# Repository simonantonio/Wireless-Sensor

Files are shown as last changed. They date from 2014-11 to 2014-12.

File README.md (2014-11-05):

Wireless Sensor Host Board
=========

This is a board used to implement wireless reporting of various sensors

Suggested Sensor Modules
---  

 - DHT22 - Temperature & Humidity  
 - TSOP4838 - IR Sensor (32khz carrier)  
 - Photo Resistor - Basic Light Levels  
 - Pulse Sensing - For use with hall effect sensors or weather stations such as [Spark Fun's Weather Station](https://www.sparkfun.com/products/8942)
 - BMP180 - Barometer & Temperature
 - Battery Voltage Monitoring
 
Results can then be transmitted to a receiver using a NRF24L01+ 

The board aims to be a low power long term sensor platform, potentially being powered from a LIPO battery directly or using a step down module such as the [Pololu Step Down Voltage Regulator](http://www.pololu.com/product/2097) 

Licensed Under the [Creative Commons Attribution-ShareAlike 3.0 Unported (CC-BY-SA 3.0)](https://creativecommons.org/licenses/by-sa/3.0/) and designed with the OSHW concepts in mind

 Intial Board Prototypes are being producted via the awesome service at [Dirty PCB's](http://dirtypcbs.com/)  
 Feel free to buy them [here](http://dirtypcbs.com/view.php?share=2637&accesskey=f92450b07b6b3961496835b5062594b2)  for $25.00USD

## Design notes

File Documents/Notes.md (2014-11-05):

Project Notes
=========

This is a very basic document containing thoughts, ideas and some notes on the wireless sensor board  
   
You will need 
----
 - ISP programmer
 - Soldering Skills (there is a reasonable amount of SMD parts sorry)
 - Parts (You should be able to get a decent amount from ebay)
 - Programming Skills. 
 
Notes
-----
Feel free to use the Arduino IDE with your ISP programmer,   
I suggest the [USBtinyISP](https://learn.adafruit.com/usbtinyisp) by adafruit
 
Project will be based fairly strongly on my experience with arduino. But will function as a standalone. 
 
TODO
----
Write the damn program.  
Setup a base station  
Debug  
Test Hardware  
Get PCB  - in progress, ordered intial prototypes on 5th November 2014  
Get Parts - in progress, ordered several parts from ebay. Need aditional minerals (or funds) to order more bits and pieces  
Write proper documentation and instructions  
Improve board layout (ideally smaller than 5x5)  
Add a through hole component version of the board to make life easier  

??  
Profit

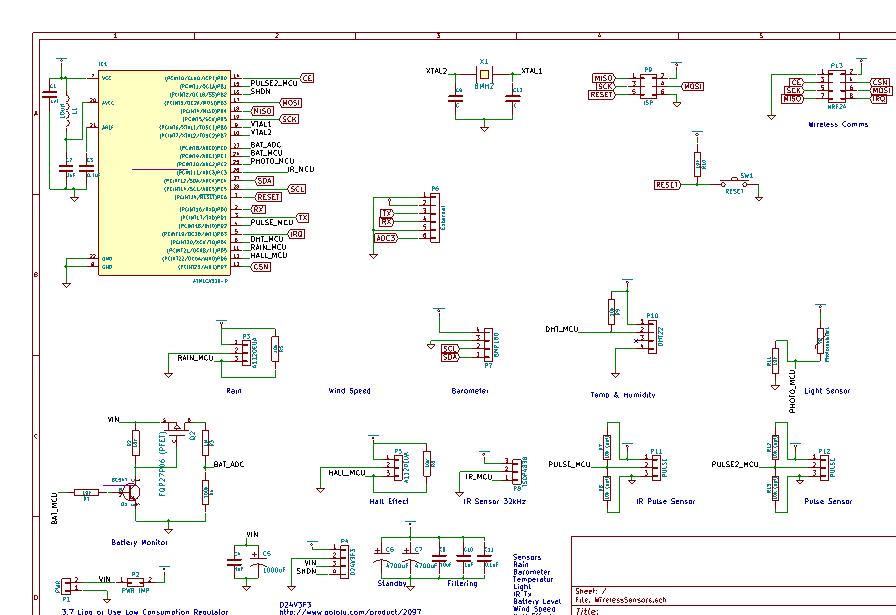
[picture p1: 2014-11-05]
Documents/Schematic.png

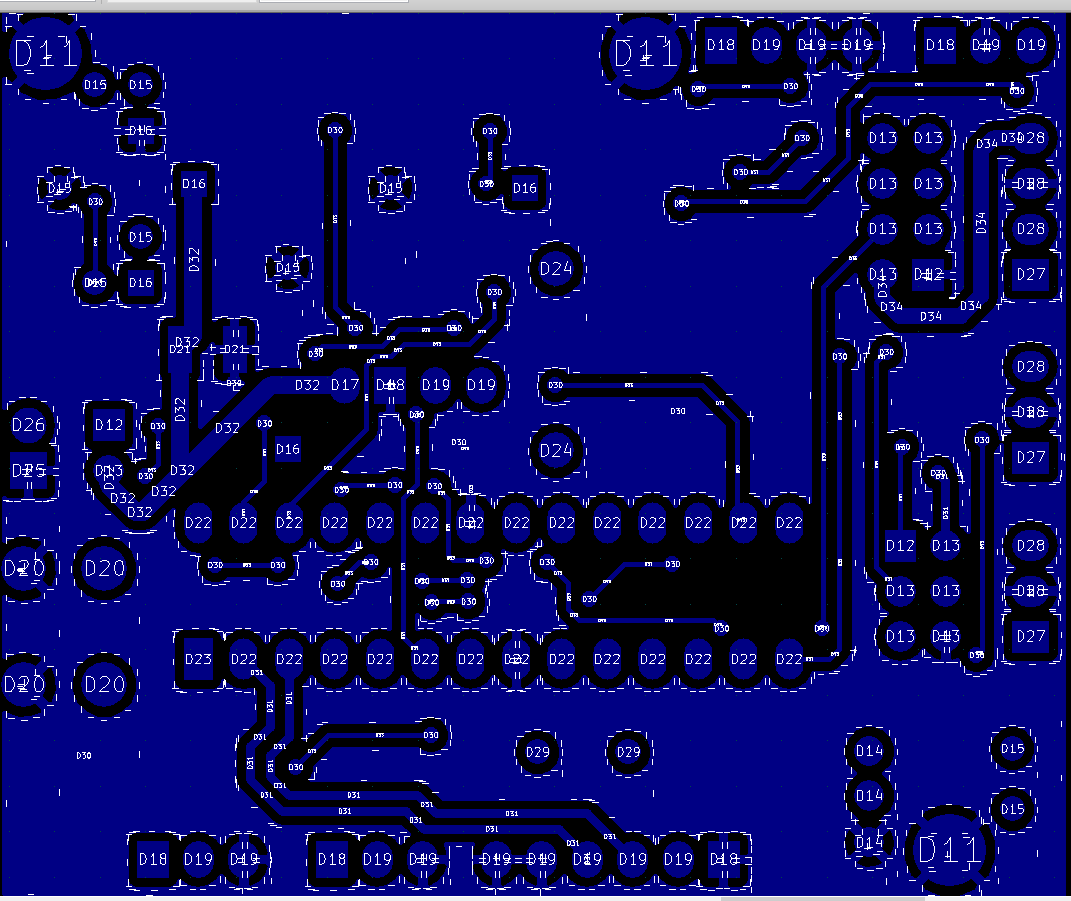
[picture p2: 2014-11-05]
Documents/Board-Cu-Bottom.png

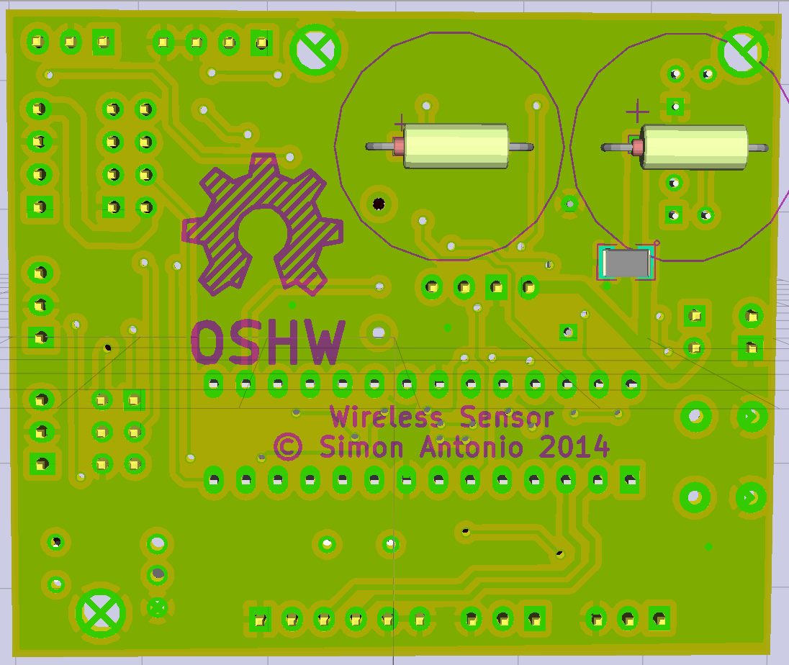
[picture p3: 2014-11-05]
Documents/Board-Bottom-3d.png

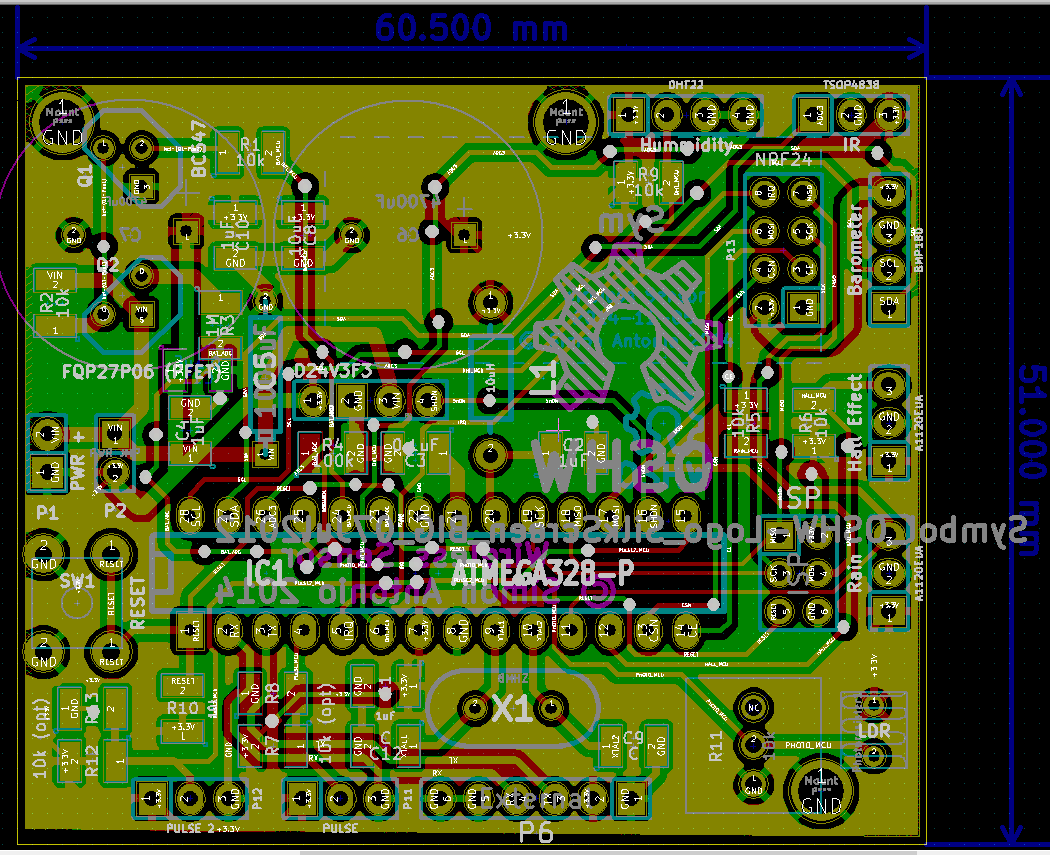
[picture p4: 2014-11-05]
Documents/Board-2d.png

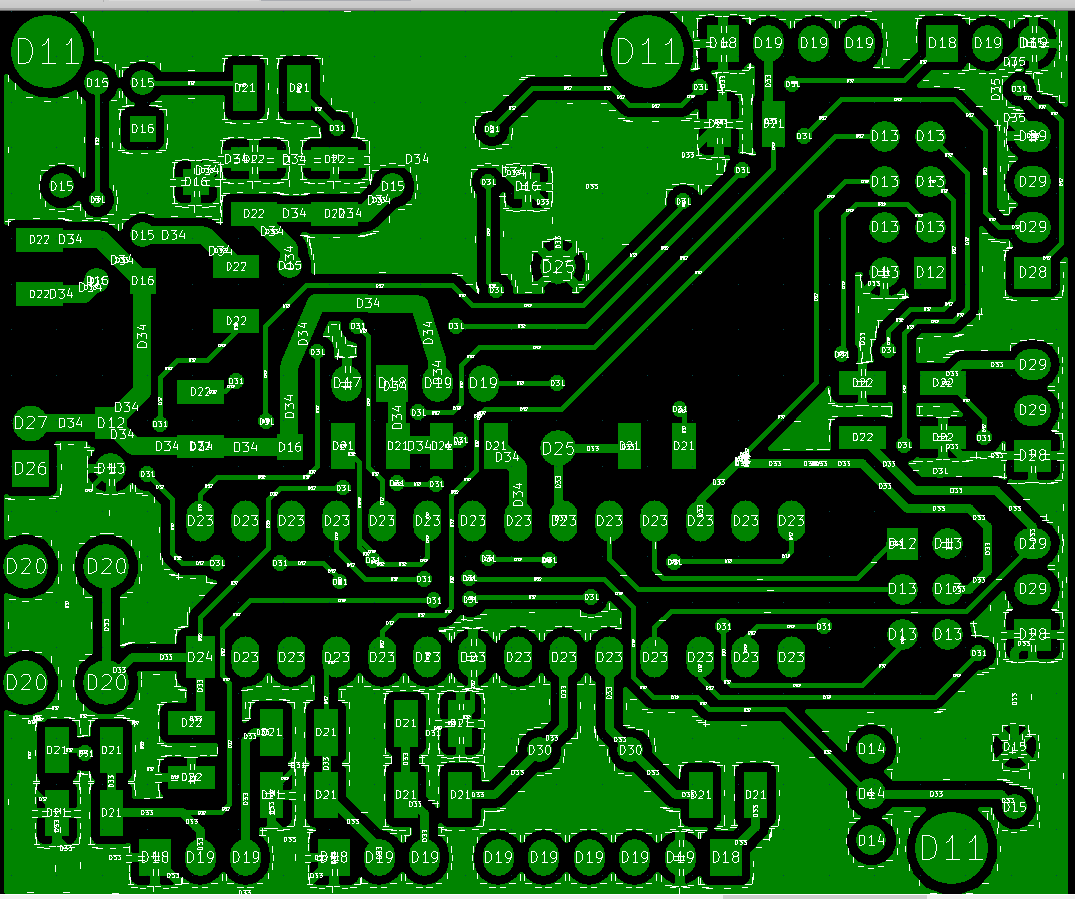
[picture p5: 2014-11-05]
Documents/Board-Cu-Top.png

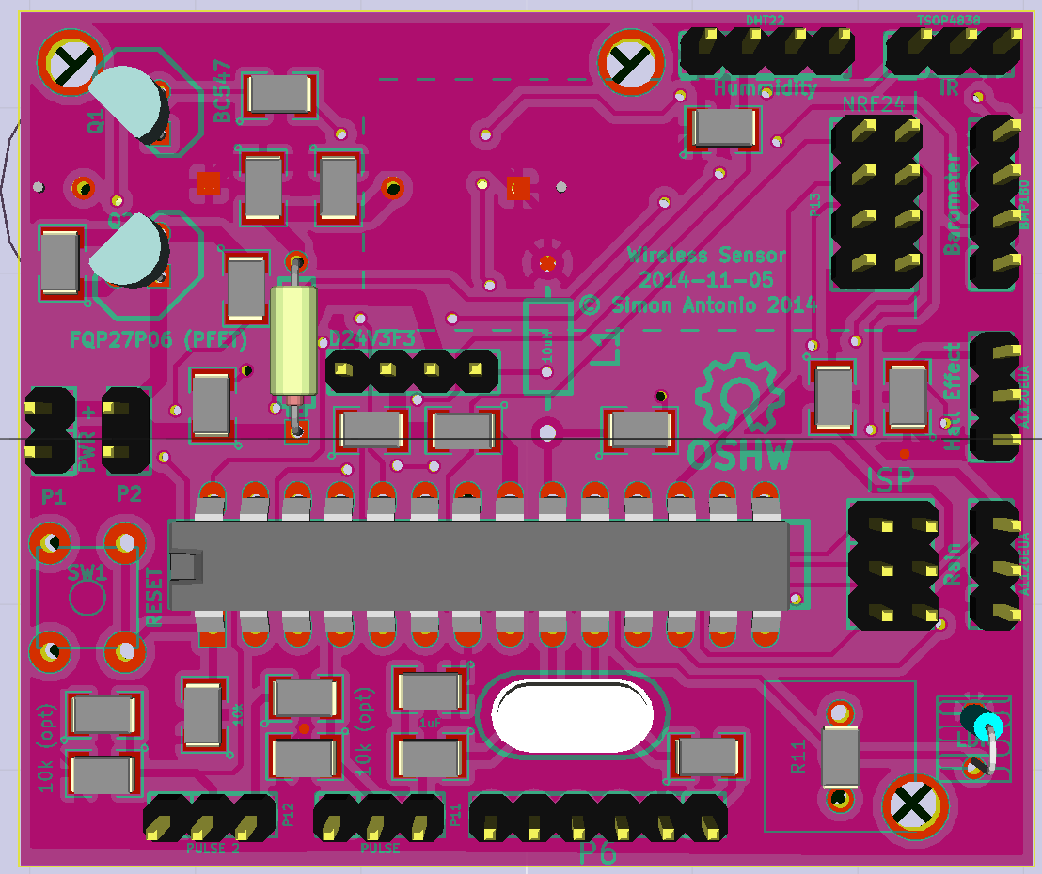
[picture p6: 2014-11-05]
Documents/Board-Top-3d.png

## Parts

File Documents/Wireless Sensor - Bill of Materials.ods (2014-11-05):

Label | Part | Footprint | Description | Link | Quantity | Price | Own Stock
C1,C2,C4,C10 | 1uF Ceramic Capacitor | 1210 - SMD |  |  | 4 |  | y
C3, C11 | 0.1uF Ceramic Cap | 1210 - SMD | can fit 805's |  | 2 |  | y
C5 | 1000uF Electrolitic | TH - up to CP4 | 25V |  | 1 |  | y
C6, C7 | 4700uF Electrolitic Cap | TH - up to CP5 | 10V |  | 2 |  | y
C9, C12 | 20pF Ceramic Cap | 1210 - SMD | to suit crystal |  | 2 |  | y
IC1 | ATMEGA328 | DIP 28 |  |  | 1
L1 | 10uH Inductor | TH | optional filter inductor
P1,P2 | 2 Pin header 0.1" |  |  |  | 2
P3,P5,P8,P11,P12 | 3 Pin header 0.1" |  |  |  | 5
P4,P7,P10 | 4 Pin header 0.1" |  |  |  | 3
P6 | 6 Pin header 0.1" |  |  |  | 1
P9 | 2x3 Pin female 0.1" |  | ISP header |  | 1
P13 | 2x4 Pin female 0.1" |  | Wireless NRF24 Connector |  | 1
Q1 | BC547 | TO92 | NPN Transistor
Q2 | FQP27P06 | TO92 | PFET
LDR1 | Photo Resistor 100k | TH | 100k, or 10k |  | 1
R1,R2,R5,R6,R9,R10 | 10k Resistor | 1210 - SMD
R7,R8,R12,R13 | 10k Resistor | 1210 - SMD | Optional
R3 | 1M Resistor | 1210 - SMD
R4 | 100k Resistor | 1210 - SMD
R11 | 10k Trimpot | TH | Three pins in a row
SW1 | Switch |  | Reset button
X1 | 8MHz Crystal | HC49 - TH | Optionally 16MHz

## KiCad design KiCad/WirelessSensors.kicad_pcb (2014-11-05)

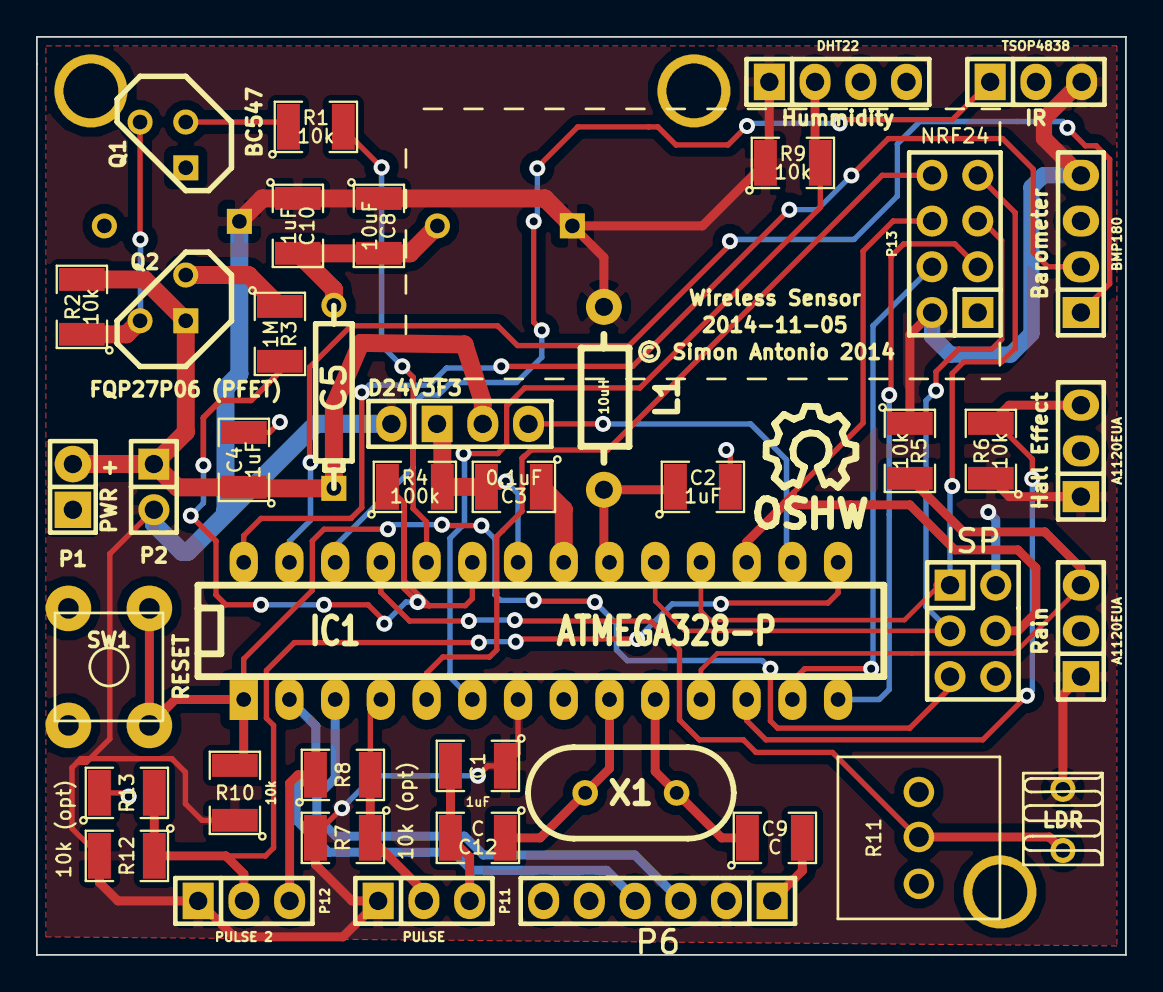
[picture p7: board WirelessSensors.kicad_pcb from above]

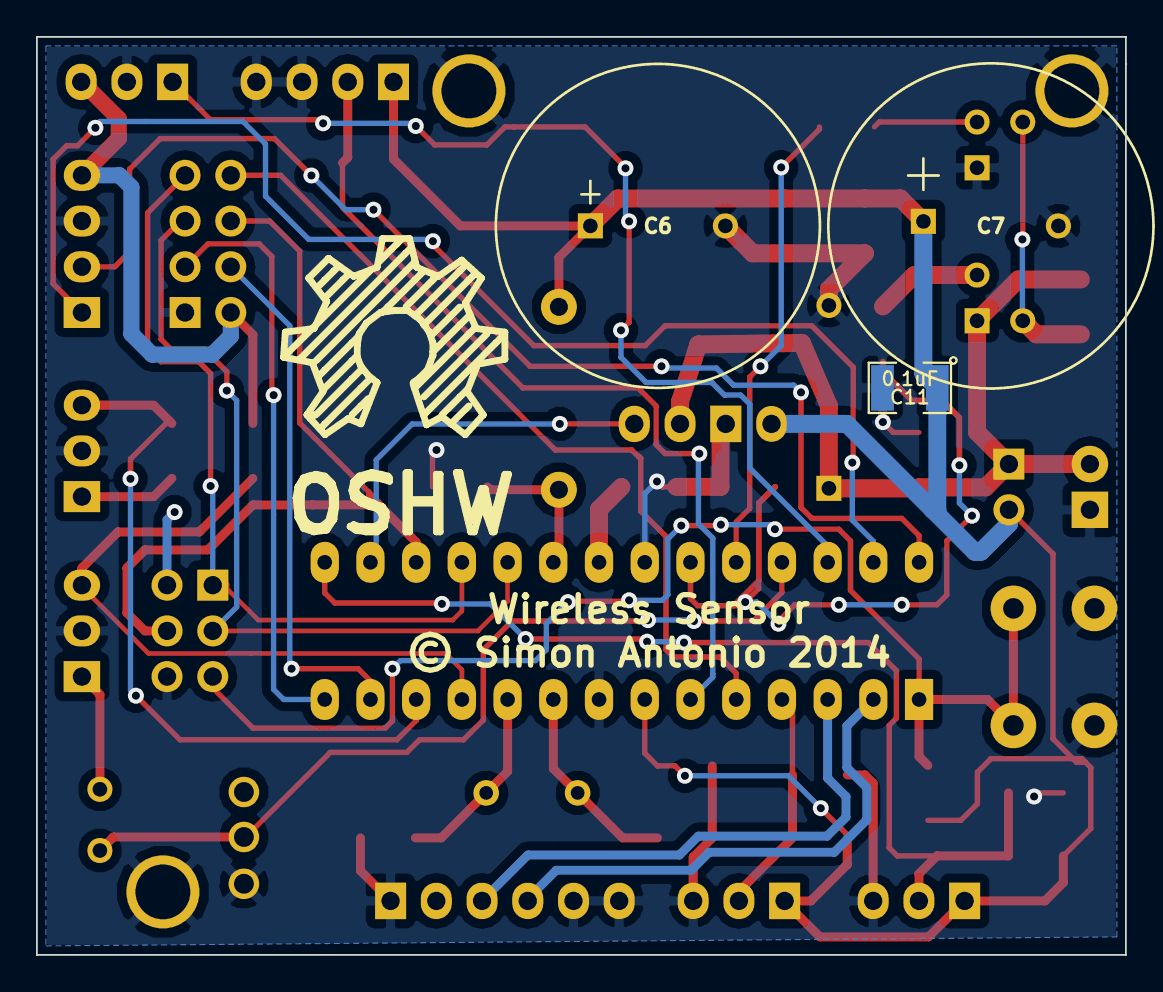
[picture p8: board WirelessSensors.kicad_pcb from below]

Board: 2 copper layers, 60.5 x 51.0 mm, 49 parts (4 on the bottom side), 31 nets.

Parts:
Barometer: BMP180; Pin_Header_Straight_1x04
C1, C2, C4, C10: 1uF; SMD-1210
C3, C11: 0.1uF; SMD-1210
C5: 1000uF; CP4
C6, C7: 4700uF; CP5
C8: 10uF; SMD-1210
C9, C12: C; SMD-1210
Hall Effect: A1120EUA; Pin_Header_Straight_1x03
Hummidity: DHT22; Pin_Header_Straight_1x04
IC1: ATMEGA328-P; DIP-28__300_ELL
IR: TSOP4838; Pin_Header_Straight_1x03
ISP: ISP; Pin_Header_Straight_2x03
L1: 10uH; Choke_Horizontal_RM10mm
Mount: P***; 1pin
Mount#2, Mount#3: P***; 1pin
P1: PWR +; Pin_Header_Straight_1x02
P2: PWR JMP; Pin_Header_Straight_2x01
P4: D24V3F3; Pin_Header_Straight_1x04
P6: External; Pin_Header_Straight_1x06
P11: PULSE; Pin_Header_Straight_1x03
P12: PULSE 2; Pin_Header_Straight_1x03
P13: NRF24; Pin_Header_Straight_2x04
Photoresister1: LDR; R1
Q1: BC547; TO92-123
Q2: FQP27P06 (PFET); TO92GSD
R1, R2, R5, R6, R9, R10, R11: 10k; SMD-1210
R3: 1M; SMD-1210
R4: 100k; SMD-1210
R7, R8, R12, R13: 10k (opt); SMD-1210
Rain: A1120EUA; Pin_Header_Straight_1x03
SW1: RESET; SW_PUSH
Sym: Symbol_OSHW-Logo_SilkScreen_BIG_07Jul2012; Symbol_OSHW-Logo_SilkScreen_BIG
X1: 8MHZ; HC-49V

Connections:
+3.3V: Barometer.4, C1.1, C6.1, C7.1, C8.1, C10.1, C11.1, Hall Effect.1, Hummidity.1, IC1.7, IR.3, ISP.2, L1.1, P2.2, P4.1, P6.2, P11.1, P12.1, P13.2, Photoresister1.1, R5.1, R6.1, R7.2, R9.1, R10.1, R12.2, Rain.1
/BAT_ADC: IC1.23, R3.2, R4.1
/BAT_MCU: IC1.24, R1.2
/DHT_MCU: Hummidity.2, IC1.6, R9.2
/HALL_MCU: Hall Effect.3, IC1.12, R6.2
/PHOTO_MCU: IC1.25, Photoresister1.2, R11.2
/PULSE2_MCU: IC1.15, P12.2, R12.1, R13.2
/PULSE_MCU: IC1.4, P11.2, R7.1, R8.2
/RAIN_MCU: IC1.11, R5.2, Rain.3
/SHDN: IC1.16, P4.4
/VIN: C4.1, C5.1, P1.2, P2.1, P4.3, Q2.S, R2.2
/XTAL1: C12.1, IC1.9, X1.2
/XTAL2: C9.1, IC1.10, X1.1
ADC3: IC1.26, IR.1
CE: IC1.14, P13.3
CSN: IC1.13, P13.4
GND: Barometer.3, C1.2, C2.2, C3.2, C4.2, C5.2, C6.2, C7.2, C8.2, C9.2, C10.2, C11.2, C12.2, Hall Effect.2, Hummidity.3, Hummidity.4, IC1.8, IC1.22, IR.2, ISP.6, Mount.1, Mount#2.1, Mount#3.1, P1.1, P4.2, P6.1, P6.5, P6.6, P11.3, P12.3, P13.1, Q1.3, R4.2, R8.1, R11.1, R13.1, Rain.2, SW1.2
IRQ: IC1.5, P13.8
MISO: IC1.18, ISP.1, P13.7
MOSI: IC1.17, ISP.4, P13.6
unnamed: C2.1, IC1.20, L1.2
unnamed: C3.1, IC1.21
unnamed: Q1.1, Q2.G, R2.1
unnamed: Q1.2, R1.1
unnamed: Q2.D, R3.1
RESET: IC1.1, ISP.5, R10.2, SW1.1
RX: IC1.2, P6.4
SCK: IC1.19, ISP.3, P13.5
SCL: Barometer.2, IC1.28
SDA: Barometer.1, IC1.27
TX: IC1.3, P6.3

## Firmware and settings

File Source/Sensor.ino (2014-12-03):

#include <SPI.h>
#include <Wire.h>
#include <DHT.h>
#include <PinChangeInt.h>

#include <SFE_BMP180.h>

#include <RHReliableDatagram.h>
#include <RH_NRF24.h>

#include <Time.h>

#include "Datagram.h"
#include "BMP180_Manager.h"
#include "Error.h"

/*
	Author:
		S.Antonio 2014-12-03
	Description:
		Board Uses Radio Head library for NRF24L01+ Wireless Transceiver
		NRF24
			CS																	PD7 [D7]
			CE																	PB0 [D8]

		BMP180																	i2c
		DHT22																	PD4 [D4]
		Sparkfun Weather Meters (SEN-08942)
			Rain																PD5 [D5]
			Pulse (add resister to high side R7)	(anometer)					PD2 [D2]
			Wind Vane (wire to ADC3 [IR])										ADC3 [A3]

		Pulse 2	(add resister to high side R12)									PB1	[D9]
		Hall																	PD6 [D6]

		Light Dependant Resister (10k)											ADC2 [A2]
		
		Optional, 
			Battery Monitoring													ADC0 [A0]
			Battery Read (Pull High)											ADC1 [A1]
			Power Shut Down (High = ON, Low = OFF)								PB2 [D10]
				Will last x seconds before caps run out of power in low power mode		-- TODO calculations and watch dog to recharge caps for standby
			TSOP4838 (IR 32kHz carrier)											ADC3 [A3]
	Notes:
		Target Arduino Pro Mini 3.3v 8MHz - Board is based of ATMEGA 328 running at 8MHz
		Either populate the D24V3F3 (pololu 3.3 regulator) or supply clean 3.3v source and add jumper to P2 (PWR_JMP)
		Typically either use the Weather Meter, or the IR sensor, but not both together.

	Libraries:
		http://www.airspayce.com/mikem/arduino/RadioHead/index.html				NRF24
		https://github.com/adafruit/DHT-sensor-library							DHT22
		https://github.com/sparkfun/BMP180_Breakout/archive/master.zip			BMP180
		http://playground.arduino.cc/Code/Time									Time
	Changes:
		N/A
	TODO:
		ppm oscillator drift offset
		remote time set
		remote query
		move user configs to seperate header
*/

//USER Configuration here

//IR or WEATHER - set false for IR sensing

#define IR_PIN A3
#define WS_WIND_DIRECTION A3
#define WS_RAIN 5
#define WS_WIND_SPEED 2

//LDR Pin
#define LDR_PIN A2

//Wireless Setup
#define NRF24_CLIENT_ADDRESS 1
#define NRF24_SERVER_ADDRESS 2

// Singleton instance of the radio driver
RH_NRF24 driver(8,7);

// Class to manage message delivery and receipt, using the driver declared above
RHReliableDatagram manager(driver, NRF24_CLIENT_ADDRESS);

//DHT22 Setup
DHT dht(4, DHT22);

//BMP180 Setup
BMP180_MANAGER bmp;
SFE_BMP180 pressure;

//Error Handler
Error err;

volatile uint8_t latest_interrupted_pin;
volatile uint8_t interrupt_count[20] = { 0 }; // 20 possible arduino pins

volatile unsigned long debounce_min = 0xffffffff;
volatile unsigned long debounce_last = 0;

void quicfunc() {
	//Test this debounce code
	long thisTime = micros() - debounce_last;
	debounce_last = micros();
	if (thisTime > 500)
	{
		latest_interrupted_pin = PCintPort::arduinoPin;
		interrupt_count[latest_interrupted_pin]++;

		if (thisTime < debounce_min)
		{
			debounce_min = thisTime;
		}

	}

	//latest_interrupted_pin = PCintPort::arduinoPin;
	//interrupt_count[latest_interrupted_pin]++;
}

void setup()
{
	if (!manager.init())
	{
		err.SetError(WIFI_ERROR);
	}
	if (!pressure.begin())
	{
		err.SetError(BMP_ERROR);
	}
	else
	{
		bmp.SetDevice(pressure);
	}

	dht.begin();

	//Setup INPUT pints (external pullups)
	pinMode(WS_RAIN, INPUT);
	pinMode(WS_WIND_DIRECTION, INPUT);
	pinMode(WS_WIND_SPEED, INPUT);

	PCintPort::attachInterrupt(WS_RAIN, &quicfunc, FALLING);  // add more attachInterrupt code as required
        PCintPort::attachInterrupt(WS_WIND_SPEED, &quicfunc, FALLING);  // add more attachInterrupt code as required
}

uint8_t nrf24_send_data[] = "BMP_T:{0}\nBMP_P:{1}\nDHT_T:{2}\nDHT_H:{3}\nWS_D:{4}\nWS_R:{5}\nWS_S:{6}\nLDR:{7}\nBAT:{8}\nP2_C{9}\nH_C:{10}";

// Dont put this on the stack:
uint8_t nrf24_response_buf[RH_NRF24_MAX_MESSAGE_LEN];

void loop()
{
	//TODO change this to SLEEP + WATCHDOG + INTERUPTS
	delay(5000);//every 5 seconds + what ever delay the folloing libs need

	DATAGRAM datagram; //clear it out

	//init datagram values to 0 where counting
	datagram.Pulse_Count = 0;
	datagram.WS_Rain_Count = 0;
	datagram.WS_Wind_Speed_Count = 0;

	//get date and time for datagram
	datagram.Day =  day();
	datagram.Hour = hour();
	datagram.Minute = minute();
	datagram.Second = second();
	datagram.Day = day();
	datagram.Month = month();
	datagram.Year = year();

	//test casting datagram to message
	//is apparently naughty will need to be tweaked/replaced later on
	uint8_t* msg = reinterpret_cast<uint8_t(&)[sizeof datagram]>(datagram);

	// Send a message to manager_server
	//if (manager.sendtoWait(nrf24_send_data, sizeof(nrf24_send_data), NRF24_SERVER_ADDRESS))
	if (manager.sendtoWait(msg, sizeof(msg), NRF24_SERVER_ADDRESS))
	{
		// Now wait for a reply from the server
		uint8_t len = sizeof(nrf24_response_buf);
		uint8_t from;
		if (manager.recvfromAckTimeout(nrf24_response_buf, &len, 2000, &from))
		{
			//server address (from)
			//from

			//response string
			//(char*)buf;

			//Add parsing for commands here
			//Check if we need to set the time 
			//Run any remote queries here
		}
		else
		{
			//No reply, is nrf24_reliable_datagram_server running?
			err.SetError(WIFI_ERROR);
		}
	}
	else
	{
		//sendtoWait failed
		err.SetError(WIFI_ERROR);
	}
	
	//DHT22
	datagram.DHT_Humidity = dht.readHumidity();
	datagram.DHT_Tempurature_C = dht.readTemperature();


	//BMP180
	bmp.LoadDatagram(datagram);
	
	//LDR
	int ldr_value;
	ldr_value = analogRead(LDR_PIN);

	//TODO - SPARKFUN WEATHER SENSORS
	if (IS_WEATHER_SENSOR)
	{
		//DO weather sensor (read A
		int wind_direction;
		wind_direction = analogRead(WS_WIND_DIRECTION);

		//Loop each pin TODO - OPTIMISE 
		//Possible issue with bouncing - TODO Debounce
		uint8_t i;
		for (i = 0; i < 20; i++) 
		{
			if (interrupt_count[i] != 0) 
			{
				if (i == WS_RAIN)
					datagram.WS_Rain_Count = interrupt_count[i];
				if (i == WS_WIND_SPEED)
					datagram.WS_Wind_Speed_Count = interrupt_count[i];
			}
		}
	}
	else
	{
		//IR sensing
	}
}

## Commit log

2014-11-05 Add the KiCad project files
    [WirelessSensors.kicad_pcb, WirelessSensors.sch]
2014-11-05 Add Bill of Materials documentation
    [Wireless Sensor - Bill of Materials.ods]
2014-11-05 Add Gerber files for production runs.
    Either via DirtyPCB's or SeeedStudio
    [WirelessSensors-B_Cu.gbl, WirelessSensors-B_Paste.gbp, WirelessSensors-B_SilkS.gbo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]
2014-11-05 Added drill file
    [WirelessSensors.drl]
2014-11-05 Updated with 3 mounting holes.
    [WirelessSensors-B_Cu.gbl, WirelessSensors-B_Paste.gbp, WirelessSensors-B_SilkS.gbo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]
2014-11-05 New mounting holes in pcb layout
    [WirelessSensors.kicad_pcb]
2014-11-05 Updated Layout Gerbers
    Includes revision info and OSHW logo
    [WirelessSensors-B_Cu.gbl, WirelessSensors-B_Paste.gbp, WirelessSensors-B_SilkS.gbo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]
2014-11-05 added additional details to PCB design
    [WirelessSensors.kicad_pcb]
2014-11-05 Board and Schematic Images
2014-11-05 Gerbers submitted to http://dirtypcbs.com/
2014-11-05 Initial docs on board
2014-12-03 Add initial commit of Arduino source code for Sensor Board
    FULLY UNTESTED and most certainly a WORK IN PROGRESS
    [Configuration.h]
2014-12-03 Add pin change interupt handling for Weather Station
    [Configuration.h]
2014-12-03 Trail version of a sloppy debounce method (no pin interrupts less than 500uS apart) will need to change this to be pin dependant.
    [Sensor.ino]

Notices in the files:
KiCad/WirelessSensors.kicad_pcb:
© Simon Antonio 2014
